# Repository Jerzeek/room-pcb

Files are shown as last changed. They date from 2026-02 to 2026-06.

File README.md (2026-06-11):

# Room Sensor



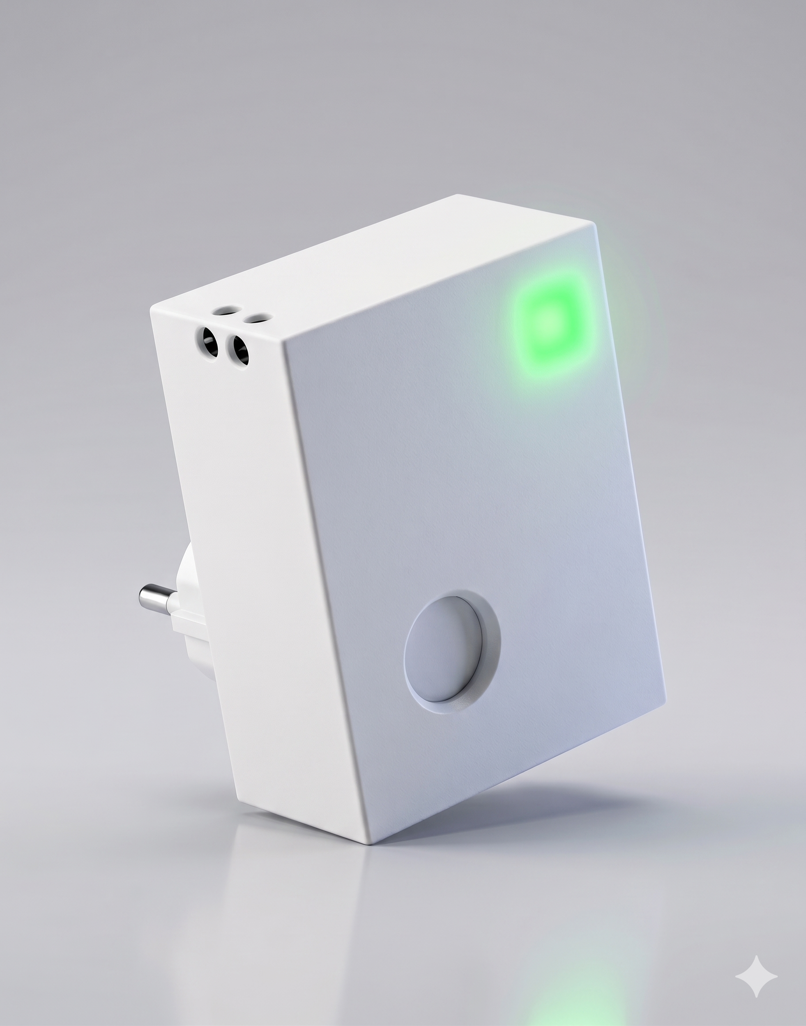
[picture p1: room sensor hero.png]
Room Sensor


An open-source, mains-powered room sensor PCB based on the ESP32-C6. Measures CO2, temperature, humidity, illuminance, and presence, with a WS2812B LED status indicator. Supports both **ESPHome** (Wi-Fi / Home Assistant) and **Zigbee** firmware out of the box.

---

> **WARNING — MAINS AC VOLTAGE**
>
> This board connects directly to mains AC (100–240 V). Incorrect wiring or handling can cause **electric shock, fire, or death**. This project is intended for **experienced makers** who are comfortable working with mains-voltage electronics. Always work with the power disconnected. Comply with all local electrical codes. The authors accept no liability for any damage or injury.

---

## Features

- Direct mains AC input via onboard HLK-5M05 AC-DC converter (no external power brick needed)
- CO2, temperature, and humidity via CozIR sensor (NDIR CO2, UART)
- Ambient light via BH1750 (I2C, lux)
- Secondary temperature + humidity via AHT20 (I2C)
- Presence/occupancy detection via LD2410 mmWave radar (UART)
- Visual CO2 status indicator: 2× WS2812B addressable LEDs
- Polyfuse (F1) overcurrent protection
- Reset/factory-reset button (BOOT pin)
- ESP32-C6 SuperMini module — supports both Wi-Fi 6 and native Zigbee
- Two equal-priority firmware options: ESPHome and Zigbee (Arduino)

## Sensors

| Sensor | Part | Interface | Measures |
|---|---|---|---|
| CO2 (NDIR) | CozIR | UART (9600 baud) | CO2 (ppm), temperature, humidity |
| Ambient light | BH1750FVI-TR | I2C (0x23) | Illuminance (lux) |
| Temperature + humidity | AHT20 | I2C | Temperature (°C), humidity (%RH) |
| Presence / occupancy | LD2410 | UART (256000 baud) | Presence, moving/stationary targets |
| Status LEDs | WS2812B-2020 × 2 | GPIO (RMT) | CO2 level indicator |

## Hardware

### Main components

| Ref | Part | Description |
|---|---|---|
| U5 | ESP32-C6 SuperMini | Main MCU — Wi-Fi 6 + Zigbee |
| PS1 | HLK-5M05 | AC-DC converter, 100–240 V AC → 5 V DC |
| U1 | CozIR | NDIR CO2 / temp / humidity sensor |
| U2 | BH1750FVI-TR | Ambient light sensor |
| U3 | AHT20 | Temperature + humidity sensor |
| J4 | 5-pin header (1.27 mm) | LD2410 radar connection |
| D1, D2 | WS2812B-2020 | Addressable RGB LEDs |
| F1 | Polyfuse | Overcurrent protection |

### Versions

| Version | Notes |
|---|---|
| v4.1 | Current release — improved silkscreen |
| v4 | Production-ready layout |
| v3.1 | Earlier revision (3D model reference) |
| v3 | Initial working prototype |

## Building / Ordering

All files needed to order and assemble the PCB are in `pcb/production/`:

| File | Purpose |
|---|---|
| `room-pcb.zip` | Gerber + drill files — upload directly to your PCB fab (JLCPCB, PCBWay, etc.) |
| `bom.csv` | Bill of materials for component sourcing |
| `positions.csv` | Pick-and-place / component placement file |
| `designators.csv` | Designator reference |
| `netlist.ipc` | IPC-D-356 netlist for electrical testing |

KiCad source files are in `pcb/`.

## Firmware

### ESPHome (Wi-Fi / Home Assistant)

Configuration is in `code/esphome/room_sensor.yaml`. A custom ESPHome component for the CozIR sensor is included under `code/esphome/components/cozir/`.

1. Copy `room_sensor.yaml` and the `components/` directory to your ESPHome config folder.
2. Create a `secrets.yaml` with your `wifi_ssid` and `wifi_password`.
3. Flash via `esphome run room_sensor.yaml`.

The LED indicates CO2 level:

| Color | CO2 |
|---|---|
| Green | < 800 ppm (good) |
| Yellow | 800–1200 ppm (moderate) |
| Red | > 1200 ppm (poor) |

Calibration buttons are exposed to Home Assistant:
- **Calibrate Fresh Air (400 ppm)** — use outdoors in clean air
- **Calibrate Nitrogen (0 ppm)** — use with pure N2

### Zigbee (Arduino / esp32-arduino)

Sketch is in `code/combined_working_zigbee/combined_working_zigbee.ino`. Requires the Arduino ESP32 core (≥ 3.x) with Zigbee support.

**Before flashing:**
- In Arduino IDE → Tools → Zigbee Mode → select **Zigbee ED (End Device)**
- Select a partition scheme that includes Zigbee (e.g., *Zigbee 4MB with spiffs*)

The sketch exposes four Zigbee endpoints:

| Endpoint | Cluster | Data |
|---|---|---|
| 10 | CO2 (CarbonDioxide) | CO2 ppm |
| 11 | Temp + Humidity | Temperature °C, humidity %RH |
| 13 | Illuminance | Lux |
| 14 | Occupancy | Presence (boolean) |

Hold the BOOT button for 3 seconds to perform a Zigbee factory reset.

## Repository layout

```
room-pcb/
├── pcb/                  KiCad project files
│   └── production/       Gerbers, BOM, placement — ready to order
├── code/
│   ├── esphome/          ESPHome YAML + custom CozIR component
│   └── combined_working_zigbee/  Arduino Zigbee sketch
├── 3Dmodels/             STEP model of the enclosure / board
├── CHANGELOG.md
├── CONTRIBUTING.md
└── LICENSE
```

## License

Hardware (PCB and schematics) is licensed under the **CERN Open Hardware Licence Version 2 — Strongly Reciprocal (CERN OHL-S v2)**. See [LICENSE](LICENSE) for the full text.

Firmware is licensed under the same CERN OHL-S v2 unless a file header states otherwise.

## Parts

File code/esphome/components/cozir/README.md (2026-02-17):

# Cozir CO2 Sensor Component for ESPHome

This component allows using Cozir CO2 sensors (like CozIR-A) with ESPHome via UART.

## Configuration

```yaml
uart:
  tx_pin: GPIO1
  rx_pin: GPIO3
  baud_rate: 9600

sensor:
  - platform: cozir
    id: my_cozir
    co2:
      name: "Cozir CO2"
    temperature:
      name: "Cozir Temperature"
    humidity:
      name: "Cozir Humidity"
    update_interval: 60s
```

## Calibration

You can calibrate the sensor using `lambda` calls or by exposing template buttons.

### Fresh Air Calibration (400ppm)
```yaml
button:
  - platform: template
    name: "Calibrate Fresh Air"
    on_press:
      - lambda: 'id(my_cozir)->calibrate_fresh_air();'
```

### Nitrogen Calibration (0ppm)
```yaml
button:
  - platform: template
    name: "Calibrate Nitrogen"
    on_press:
      - lambda: 'id(my_cozir)->calibrate_nitrogen();'
```

### Known Gas Calibration
```yaml
# Example using a template number to set target PPM
number:
  - platform: template
    id: target_ppm
    name: "Target Calibration PPM"
    min_value: 0
    max_value: 5000
    step: 10
    optimistic: true
    set_action: []

button:
  - platform: template
    name: "Calibrate Known Gas"
    on_press:
      - lambda: 'id(my_cozir)->calibrate_known_gas((uint16_t)id(target_ppm).state);'
```

## Notes
- The component automatically detects the PPM multiplier (1, 10, or 100) on each update.
- Ensure the sensor is powered correctly (3.3V typically).

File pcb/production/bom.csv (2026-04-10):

Designator | Footprint | Quantity | Value | LCSC Part #
C1 | 0805 | 1 | 1U
C4, C5, C6 | 0805 | 3 | 0.1U
D1, D2 | LED_WS2812B-2020_PLCC4_2.0x2.0mm | 2 | WS2812B
F1 | Fuse_Bourns_MF-RG300 | 1 | Polyfuse
J2 | JST_PH_S2B-PH-SM4-TB_1x02-1MP_P2.00mm_Horizontal | 1 | Conn_01x02
J3 | JST_SH_SM04B-SRSS-TB_1x04-1MP_P1.00mm_Horizontal | 1 | Conn_01x04
J4 | PinHeader_1x05_P1.27mm_Vertical | 1 | Conn_01x05
J5, J6 | PinHeader_1x04_P2.54mm_Vertical | 2 | Conn_01x04
PS1 | Converter_ACDC_Hi-Link_HLK-5Mxx | 1 | HLK-5M05
R1 | 0805 | 1 | 1K
R5, R6, R7 | 0805 | 3 | 10K
TP1, TP2, TP3 | TestPoint_THTPad_D1.5mm_Drill0.7mm | 3 | TestPoint
U1 | cozir | 1 | COZIR
U2 | XDCR_BH1750FVI-TR | 1 | BH1750FVI-TR
U3 | PSON100P300X300X110-6N | 1 | AHT20
U5 | MODULE_ESP32-C6_SUPERMINI_TH | 1 | ESP32-C6_SUPERMINI_TH

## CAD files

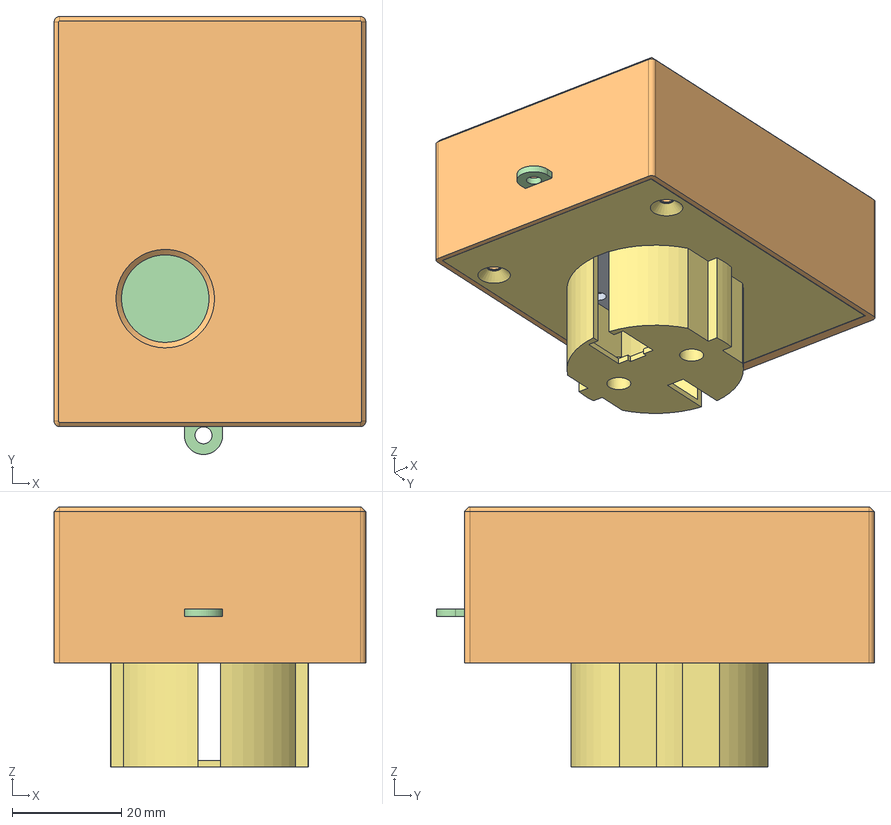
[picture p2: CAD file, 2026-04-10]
3Dmodels/home sensor v31.step
57.0 x 80.1 x 47.5 mm
pcb
housing
hilink acdc
cozir
LD2410
esp32 c6 super mini
ac

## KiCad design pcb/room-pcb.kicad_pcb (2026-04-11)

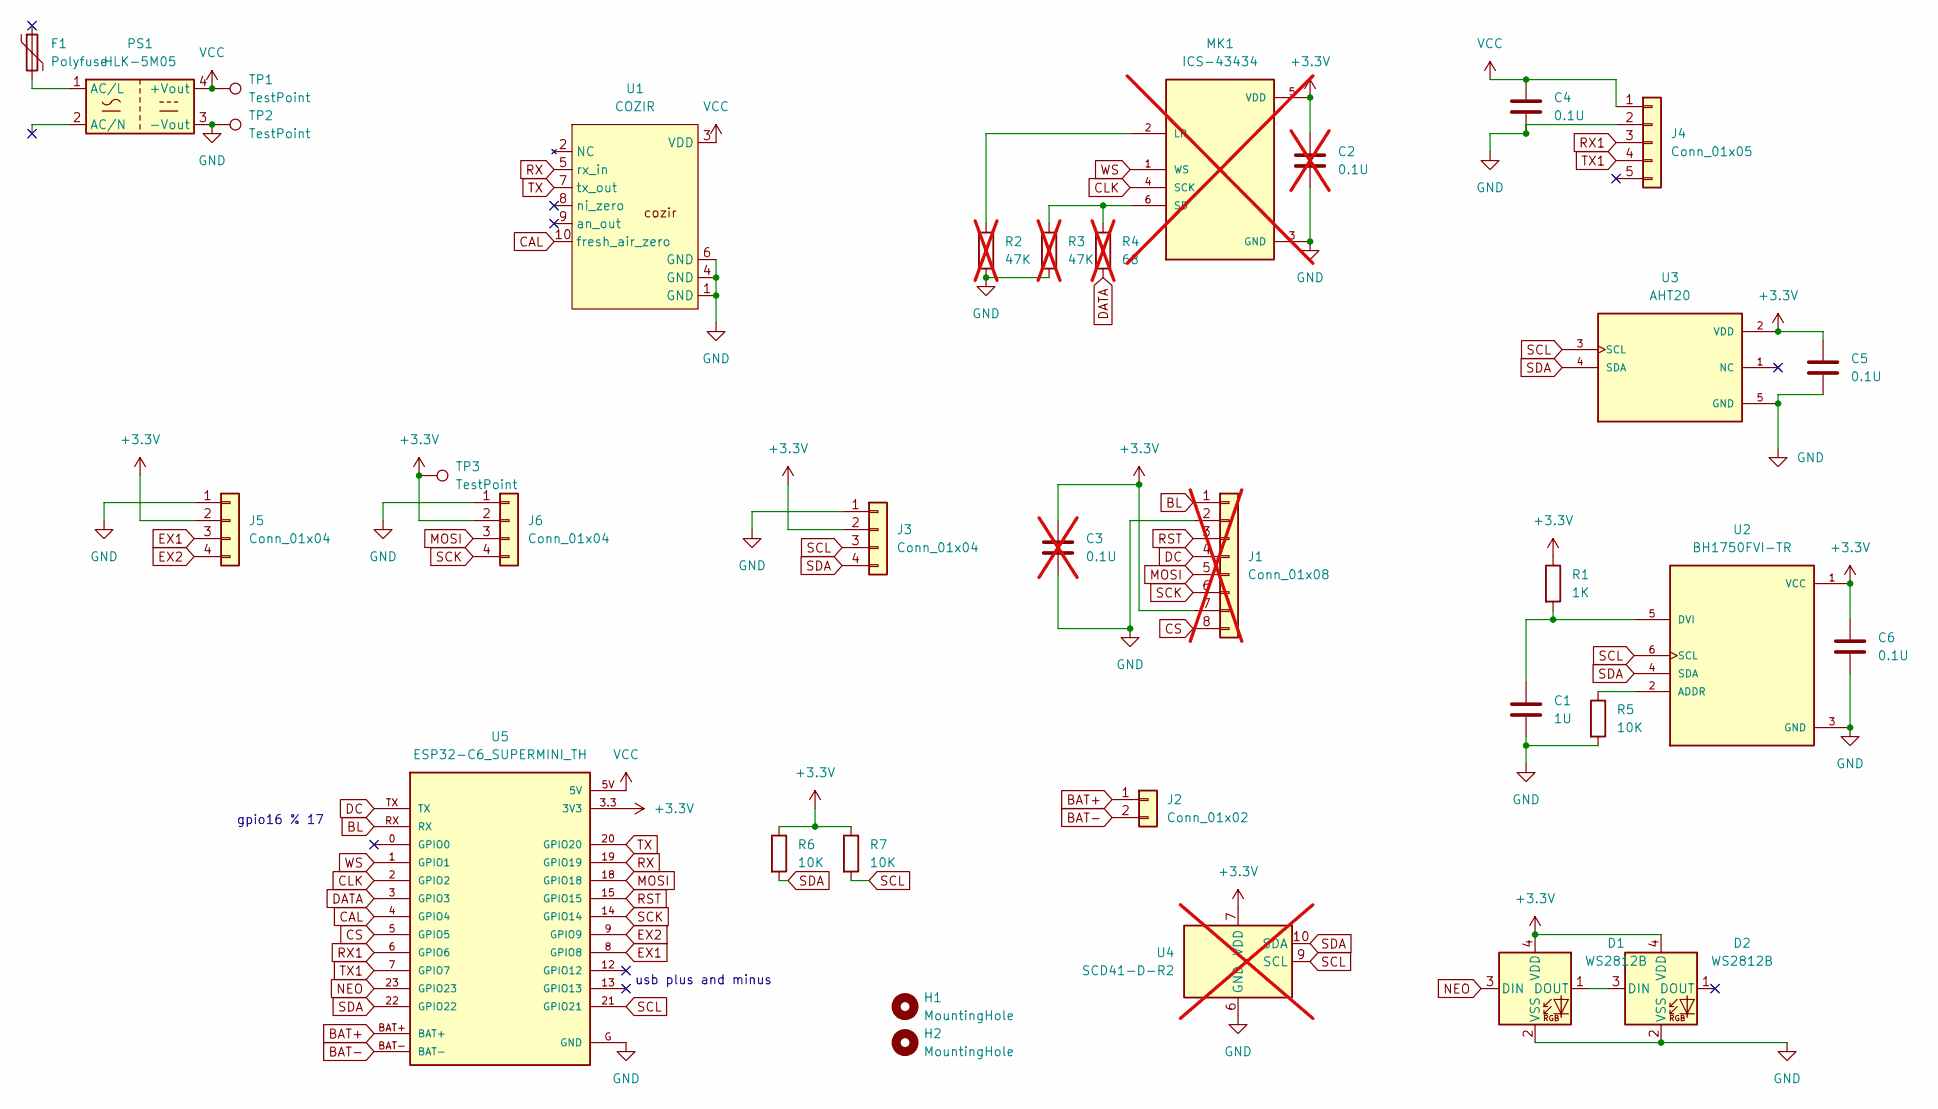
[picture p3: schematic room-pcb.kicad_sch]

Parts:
C1: 1U; C_0805_2012Metric
C2, C3: 0.1U; C_0805_2012Metric; not fitted
C4, C5, C6: 0.1U; C_0805_2012Metric
D1, D2: WS2812B; LED_WS2812B-2020_PLCC4_2.0x2.0mm
F1: Polyfuse; Fuse_Bourns_MF-RG300
H1, H2: MountingHole; MountingHole_3.2mm_M3
J1: Conn_01x08; Hirose_FH12-8S-0.5SH_1x08-1MP_P0.50mm_Horizontal; not fitted
J2: Conn_01x02; JST_PH_S2B-PH-SM4-TB_1x02-1MP_P2.00mm_Horizontal
J3: Conn_01x04; JST_SH_SM04B-SRSS-TB_1x04-1MP_P1.00mm_Horizontal
J4: Conn_01x05; PinHeader_1x05_P1.27mm_Vertical
J5, J6: Conn_01x04; PinHeader_1x04_P2.54mm_Vertical
MK1: ICS-43434; MIC_ICS-43434; not fitted
PS1: HLK-5M05; Converter_ACDC_Hi-Link_HLK-5Mxx
R1: 1K; R_0805_2012Metric
R2, R3: 47K; R_0805_2012Metric; not fitted
R4: 68; R_0805_2012Metric; not fitted
R5, R6, R7: 10K; R_0805_2012Metric
TP1, TP2, TP3: TestPoint; TestPoint_THTPad_D1.5mm_Drill0.7mm
U1: COZIR; cozir
U2: BH1750FVI-TR; XDCR_BH1750FVI-TR; PARTREV D
U3: AHT20; PSON100P300X300X110-6N; PARTREV V1.0
U4: SCD41-D-R2; Sensirion_SCD4x-1EP_10.1x10.1mm_P1.25mm_EP4.8x4.8mm; not fitted
U5: ESP32-C6_SUPERMINI_TH; MODULE_ESP32-C6_SUPERMINI_TH

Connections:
+3.3V: C2.1, C3.1, C5.1, C6.1, D1.4 (VDD), D2.4 (VDD), J1.7, J3.2, J5.2, J6.2, MK1.5 (VDD), R1.1, R6.1, R7.1, TP3.1, U2.1 (VCC), U3.2 (VDD), U4.7 (VDD), U4.19 (VDD), U5.3.3 (3V3)
BAT+: J2.1, U5.BAT+
BAT-: J2.2, U5.BAT-
BL: J1.1, U5.RX
CAL: U1.10 (fresh_air_zero), U5.4 (GPIO4)
CLK: MK1.4 (SCK), U5.2 (GPIO2)
CS: J1.8, U5.5 (GPIO5)
DATA: R4.2, U5.3 (GPIO3)
DC: J1.4, U5.TX
EX1: J5.3, U5.8 (GPIO8)
EX2: J5.4, U5.9 (GPIO9)
GND: C1.2, C2.2, C3.2, C4.2, C5.2, C6.2, D1.2 (VSS), D2.2 (VSS), J1.2, J3.1, J4.2, J5.1, J6.1, MK1.3 (GND), PS1.3 (-Vout), R2.2, R3.2, R5.2, TP2.1, U1.1 (GND), U1.4 (GND), U1.6 (GND), U2.3 (GND), U3.5 (GND), U4.6 (GND), U4.20 (GND), U4.21 (GND), U5.G (GND)
MOSI: J1.5, J6.3, U5.18 (GPIO18)
NEO: D1.3 (DIN), U5.23 (GPIO23)
unnamed: D1.1 (DOUT), D2.3 (DIN)
unnamed: MK1.2 (LR), R2.1
unnamed: MK1.6 (SD), R3.1, R4.1
unnamed: F1.2, PS1.1 (AC/L)
unnamed: R5.1, U2.2 (ADDR)
unnamed: C1.1, R1.2, U2.5 (DVI)
RST: J1.3, U5.15 (GPIO15)
RX: U1.5 (rx_in), U5.19 (GPIO19)
RX1: J4.3, U5.6 (GPIO6)
SCK: J1.6, J6.4, U5.14 (GPIO14)
SCL: J3.3, R7.2, U2.6 (SCL), U3.3 (SCL), U4.9 (SCL), U5.21 (GPIO21)
SDA: J3.4, R6.2, U2.4 (SDA), U3.4 (SDA), U4.10 (SDA), U5.22 (GPIO22)
TX: U1.7 (tx_out), U5.20 (GPIO20)
TX1: J4.4, U5.7 (GPIO7)
VCC: C4.1, J4.1, PS1.4 (+Vout), TP1.1, U1.3 (VDD), U5.5V
WS: MK1.1 (WS), U5.1 (GPIO1)

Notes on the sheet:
gpio16 % 17
usb plus and minus

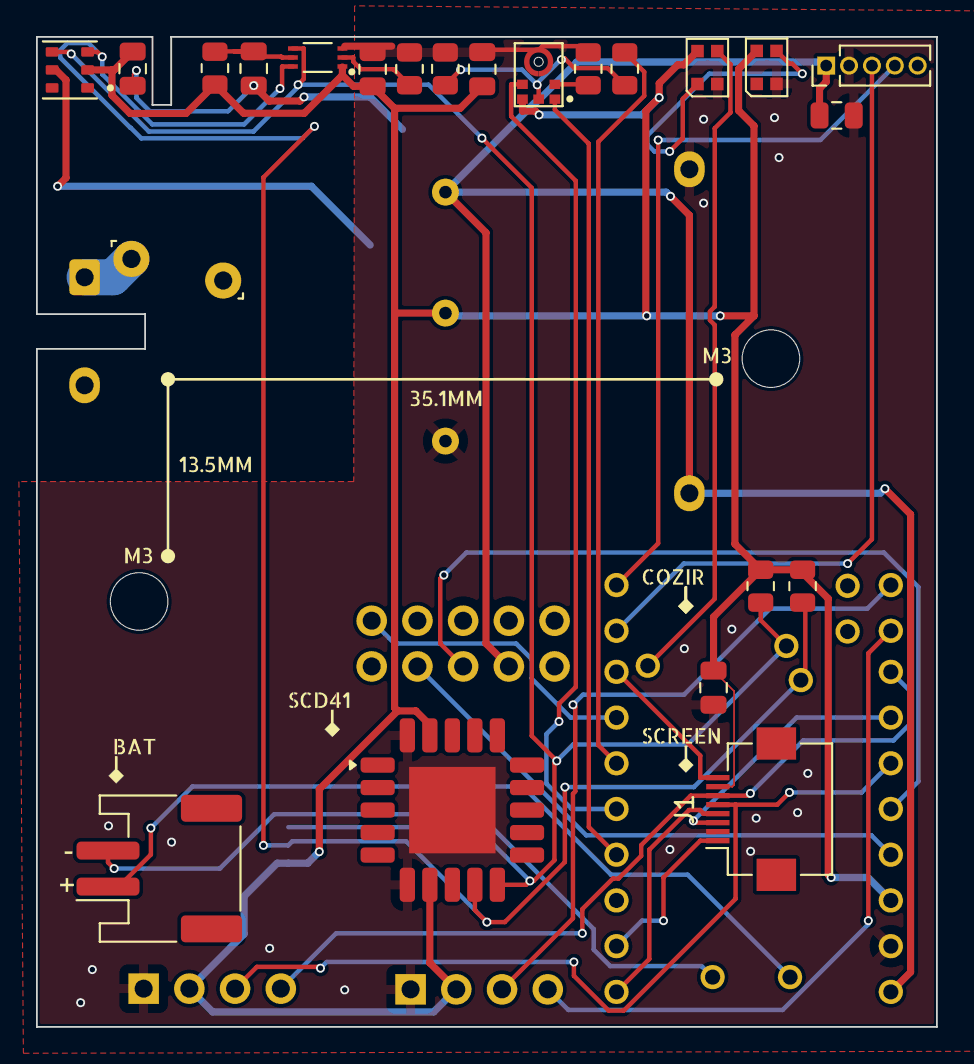
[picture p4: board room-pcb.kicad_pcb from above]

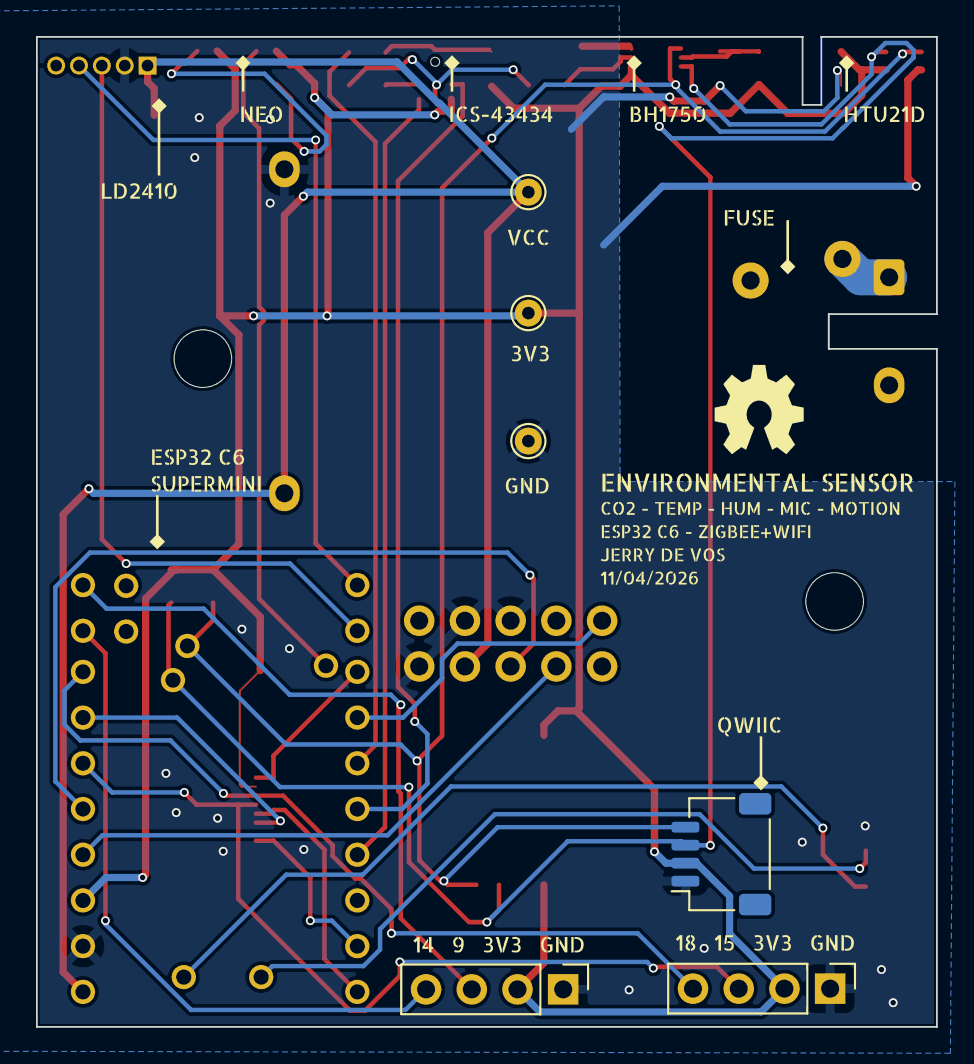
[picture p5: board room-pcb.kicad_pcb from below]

Board: 2 copper layers, 50.0 x 55.0 mm, 34 parts (7 on the bottom side), 30 nets.

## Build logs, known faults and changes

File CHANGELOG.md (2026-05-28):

# Changelog

All notable changes to this project will be documented in this file.

The format is based on [Keep a Changelog](https://keepachangelog.com/en/1.1.0/).
Hardware versions follow a `vMAJOR.MINOR` scheme; minor bumps are layout/silkscreen changes, major bumps indicate schematic changes.

---

## [Unreleased]

---

## [v4.1] - 2026-04

### Changed
- Improved silkscreen legibility — component labels and reference designators cleaned up across the board.
- Updated Gerbers and production files to match v4.1 layout.

---

## [v4] - 2026-03

### Added
- Production-ready layout with all sensors placed and routed.
- HLK-5M05 footprint corrected and mains clearances verified.
- Polyfuse (F1) added for overcurrent protection on the 5 V rail.
- LD2410 radar header (J4, 1.27 mm pitch, 5-pin) added.
- JST-SH connector (J3) for I2C breakout.
- Two WS2812B-2020 LEDs (D1, D2) as CO2 status indicators.
- Combined working Zigbee sketch (`combined_working_zigbee.ino`) with CO2, temp/humidity, illuminance, and occupancy endpoints.
- ESPHome configuration (`room_sensor.yaml`) with custom CozIR component.

### Changed
- Switched MCU to ESP32-C6 SuperMini module for native Zigbee support.
- Resolved KiCad merge conflicts from concurrent edits.

---

## [v3.1] - 2026-02

### Changed
- Minor layout adjustments (captured in STEP model `home sensor v31.step`).
- Test points (TP1–TP3) repositioned for easier probing.

---

## [v3] - 2026-01

### Added
- Initial working prototype with all sensor ICs populated.
- First ESPHome YAML and CozIR Arduino library integrated.
- 3D model added to repository.

---

[Unreleased]: https://github.com/Jerzeek/room-pcb/compare/v4.1...HEAD
[v4.1]: https://github.com/Jerzeek/room-pcb/compare/v4...v4.1
[v4]: https://github.com/Jerzeek/room-pcb/compare/v3.1...v4
[v3.1]: https://github.com/Jerzeek/room-pcb/compare/v3...v3.1
[v3]: https://github.com/Jerzeek/room-pcb/releases/tag/v3

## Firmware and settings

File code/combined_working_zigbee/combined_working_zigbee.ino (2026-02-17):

/*
 * Combined Room Sensors Sketch (Zigbee End Device)
 * - Cozir CO2 Sensor (SoftwareSerial on 20/19)
 * - LD2410 Radar Sensor (Hardware Serial)
 * - BH1750 Light Sensor (I2C on 22/21)
 * - NeoPixel Status LED (Pin 8)
 * - Zigbee Endpoints: CO2, Temp+Hum, Light, Occupancy
 *
 * NOTE: Select "Zigbee ED (End Device)" in Tools -> Zigbee Mode
 * NOTE: Select a Partition Scheme with Zigbee (e.g., "Zigbee 4MB with spiffs")
 */

#ifndef ZIGBEE_MODE_ED
#error "Zigbee end device mode is not selected in Tools->Zigbee mode"
#endif

#include "Arduino.h"
#include "Zigbee.h"
#include <Wire.h>
#include <SoftwareSerial.h>
#include <Adafruit_NeoPixel.h>

// --- Libraries ---
#include "cozir.h"
#include <ld2410.h>
#include <BH1750.h>

// --- FILTERING CLASS ---
template <typename T, int SIZE>
class MovingQuantile {
  T buffer[SIZE];
  uint8_t idx = 0;
  uint8_t count = 0;
  float quantile;

public:
  MovingQuantile(float q = 0.5) : quantile(q) {}

  void add(T value) {
    buffer[idx] = value;
    idx = (idx + 1) % SIZE;
    if (count < SIZE) count++;
  }

  T get() {
    if (count == 0) return 0;
    T sorted[SIZE];
    for (uint8_t i = 0; i < count; i++) sorted[i] = buffer[i];
    // Simple Bubble Sort
    for (uint8_t i = 0; i < count - 1; i++) {
      for (uint8_t j = 0; j < count - i - 1; j++) {
        if (sorted[j] > sorted[j + 1]) {
          T temp = sorted[j];
          sorted[j] = sorted[j + 1];
          sorted[j + 1] = temp;
        }
      }
    }
    int qIdx = (int)(quantile * (count - 1));
    return sorted[qIdx];
  }
};

// --- ZIGBEE CONFIG ---
#define EP_CO2 10
#define EP_TEMP_HUM 11  // Combined endpoint for Temp & Humidity
#define EP_LIGHT 13
#define EP_OCCUPANCY 14

uint8_t button = BOOT_PIN; 

// Create Zigbee Sensor Objects
ZigbeeCarbonDioxideSensor zbCo2(EP_CO2);
ZigbeeTempSensor          zbTempHum(EP_TEMP_HUM); // Handles both Temp and Hum
ZigbeeIlluminanceSensor   zbLight(EP_LIGHT);
ZigbeeOccupancySensor     zbOcc(EP_OCCUPANCY);

// --- PIN DEFINITIONS & OBJECTS ---

// 1. Cozir CO2 (SoftwareSerial)
SoftwareSerial sws(20, 19); //RX TX
COZIR czr(&sws);
C0ZIRParser czrp;

// 2. BH1750 Light Sensor (I2C)
BH1750 lightMeter(0x5C);

// 3. NeoPixel (Pin 8)
#define NEOPIXEL_PIN 8
#define NUMPIXELS 1
Adafruit_NeoPixel pixels(NUMPIXELS, NEOPIXEL_PIN, NEO_GRB + NEO_KHZ800);

// 4. LD2410 Radar (Hardware Serial)
#define MONITOR_SERIAL Serial
#define RADAR_SERIAL Serial1
#define RADAR_RX_PIN 7
#define RADAR_TX_PIN 5 
ld2410 radar;

// --- TIMERS ---
uint32_t lastRadarReport = 0;
uint32_t lastCozirReport = 0;
uint32_t lastLightReport = 0;

// --- FILTERING ---
MovingQuantile<uint32_t, 5> co2Filter(0.5);
MovingQuantile<float, 5> tempFilter(0.5);
MovingQuantile<float, 5> humFilter(0.5);
MovingQuantile<float, 5> lightFilter(0.5);

const uint32_t RADAR_REPORT_INTERVAL = 1000;
const uint32_t COZIR_REPORT_INTERVAL = 5000;
const uint32_t LIGHT_REPORT_INTERVAL = 20000;

void setup()
{
  // 1. Monitor Serial
  MONITOR_SERIAL.begin(115200);
  delay(2000);
  MONITOR_SERIAL.println(F("\n--- Combined Room Sensors (Zigbee ED) Init ---"));

  // 2. Button Init
  pinMode(button, INPUT_PULLUP);

  // 3. NeoPixel Init
  MONITOR_SERIAL.println(F("[NeoPixel] Init..."));
  pixels.begin();
  pixels.show(); 

  // 4. Cozir Setup
  MONITOR_SERIAL.println(F("[Cozir] Init..."));
  sws.begin(9600);
  czr.init();
  czrp.init();
  czr.setOperatingMode(CZR_STREAMING);
  czr.setOutputFields(CZR_DEFAULT);

  // 5. BH1750 Setup
  MONITOR_SERIAL.println(F("[BH1750] Init..."));
  Wire.begin(22, 21); 
  if (lightMeter.begin()) {
    MONITOR_SERIAL.println(F("[BH1750] OK"));
  } else {
    MONITOR_SERIAL.println(F("[BH1750] Error initialising"));
  }

  // 6. Radar Setup
  MONITOR_SERIAL.print(F("[Radar] Connecting to RX:"));
  MONITOR_SERIAL.print(RADAR_RX_PIN);
  MONITOR_SERIAL.print(F(" TX:"));
  MONITOR_SERIAL.println(RADAR_TX_PIN);

  #if defined(ESP32)
    RADAR_SERIAL.begin(256000, SERIAL_8N1, RADAR_RX_PIN, RADAR_TX_PIN);
  #elif defined(__AVR_ATmega32U4__)
    RADAR_SERIAL.begin(256000);
  #endif

  if(radar.begin(RADAR_SERIAL))
  {
    MONITOR_SERIAL.println(F("[Radar] OK"));
  }
  else
  {
    MONITOR_SERIAL.println(F("[Radar] Not connected"));
  }

  // 7. Zigbee Setup
  MONITOR_SERIAL.println(F("[Zigbee] Init..."));
  
  // Set Info
  zbCo2.setManufacturerAndModel("Espressif", "MultiSensor_CO2");
  
  // Configure Combined Temp/Hum Sensor
  zbTempHum.setManufacturerAndModel("Espressif", "MultiSensor_TempHum");
  // Enable Humidity on this sensor (Min:0%, Max:100%, Tolerance:1%)
  zbTempHum.addHumiditySensor(0, 100, 1.0); 

  zbLight.setManufacturerAndModel("Espressif", "MultiSensor_Light");
  zbOcc.setManufacturerAndModel("Espressif", "MultiSensor_Occ");

  // Add Endpoints
  Zigbee.addEndpoint(&zbCo2);
  Zigbee.addEndpoint(&zbTempHum);
  Zigbee.addEndpoint(&zbLight);
  Zigbee.addEndpoint(&zbOcc);

  if (!Zigbee.begin()) {
    MONITOR_SERIAL.println(F("[Zigbee] Failed to start! Rebooting..."));
    ESP.restart();
  } else {
    MONITOR_SERIAL.println(F("[Zigbee] Started successfully!"));
  }
  
  MONITOR_SERIAL.println(F("[Zigbee] Connecting to network..."));
  while (!Zigbee.connected()) {
    MONITOR_SERIAL.print(".");
    delay(100);
  }
  MONITOR_SERIAL.println();
  
  // Configure Reporting
  zbCo2.setReporting(1, 30, 10);     
  
  // Temp Reporting (Min, Max, Delta)
  zbTempHum.setReporting(1, 30, 0.5);   
  // Humidity Reporting (Min, Max, Delta) - Separate function
  zbTempHum.setHumidityReporting(1, 30, 1.0);
  
  zbLight.setReporting(1, 30, 50);   
  
  // NOTE: zbOcc (Binary Sensor) usually reports on state change automatically. 
  // Removed setReporting() as it is not supported by the Occupancy class.

  MONITOR_SERIAL.println(F("--- Setup Complete ---\n"));
}

void loop()
{
  // --- READ RADAR (Must be called frequently) ---
  radar.read();

  uint32_t currentMillis = millis();

  // --- REPORT RADAR & UPDATE NEOPIXEL ---
  if(radar.isConnected() && (currentMillis - lastRadarReport > RADAR_REPORT_INTERVAL))
  {
    lastRadarReport = currentMillis;
    bool presence = radar.presenceDetected();
    
    // Update Zigbee
    zbOcc.setOccupancy(presence);
    
    if(presence)
    {
      pixels.setPixelColor(0, pixels.Color(255, 0, 0)); // Red
      
      // if(radar.stationaryTargetDetected())
      // {
      //   MONITOR_SERIAL.print(F("[Radar] Stat Dist: "));
      //   MONITOR_SERIAL.print(radar.stationaryTargetDistance());
      //   MONITOR_SERIAL.print(F("cm Energy: "));
      //   MONITOR_SERIAL.print(radar.stationaryTargetEnergy());
      //   MONITOR_SERIAL.print(' ');
      // }
      // if(radar.movingTargetDetected())
      // {
      //   MONITOR_SERIAL.print(F("[Radar] Mov Dist: "));
      //   MONITOR_SERIAL.print(radar.movingTargetDistance());
      //   MONITOR_SERIAL.print(F("cm Energy: "));
      //   MONITOR_SERIAL.print(radar.movingTargetEnergy());
      // }
      // MONITOR_SERIAL.println();
    }
    else
    {
      pixels.setPixelColor(0, pixels.Color(0, 255, 0)); // Green
      MONITOR_SERIAL.println(F("[Radar] No target"));
    }
    pixels.show();
  }

  // --- READ COZIR STREAM ---


  // --- REPORT COZIR (Serial Monitor) ---
  if (currentMillis - lastCozirReport > COZIR_REPORT_INTERVAL) {
    lastCozirReport = currentMillis;

    while (sws.available()) {
      int field = czrp.nextChar(sws.read());
      if (field != 0) {
        // Filter CO2 (Max 4000)
        if (field == 'Z') {
          uint32_t co2 = czrp.CO2();
          if (co2 <= 4000) {
            co2Filter.add(co2);
            zbCo2.setCarbonDioxide(co2Filter.get());
          }
        }
        // Filter Temp (0-100 C)
        else if (field == 'T') {
          float t = czrp.celsius();
          if (t >= 0 && t <= 100) {
            tempFilter.add(t);
            zbTempHum.setTemperature(tempFilter.get());
          }
        }
        // Filter Humidity
        else if (field == 'H') {
          float h = czrp.humidity();
          if (h >= 0 && h <= 100) {
            humFilter.add(h);
            zbTempHum.setHumidity(humFilter.get());
          }
        }
      }
    }
    uint32_t c = czrp.CO2(); 
    float t = czrp.celsius();
    float h = czrp.humidity();

    MONITOR_SERIAL.print(F("[Cozir] Temp: "));
    MONITOR_SERIAL.print(t);
    MONITOR_SERIAL.print(F(" C\tHum: "));
    MONITOR_SERIAL.print(h);
    MONITOR_SERIAL.print(F("%\tCO2: "));
    MONITOR_SERIAL.println(c);
  }

  // --- REPORT LIGHT ---
  if (currentMillis - lastLightReport > LIGHT_REPORT_INTERVAL) {
    lastLightReport = currentMillis;
      
      float lux = lightMeter.readLightLevel();
      lightFilter.add(lux);
      float filteredLux = lightFilter.get();
      
      // 1. Calculate the Zigbee "MeasuredValue"
      // Formula: 10000 * log10(Lux) + 1
      uint16_t zigbeeRaw;
      
      if (filteredLux <= 0.0001) { 
        zigbeeRaw = 0; // Darkness
      } else if (filteredLux > 1000000) {
        zigbeeRaw = 0xfffe; // Maximum defined value
      } else {
        zigbeeRaw = (uint16_t)(10000 * log10(filteredLux) + 1);
      }

      // 2. Log both for debugging
      MONITOR_SERIAL.print(F("[Light] Real Lux: "));
      MONITOR_SERIAL.println(lux);
      // MONITOR_SERIAL.print(F(" | Zigbee Raw: "));
      // MONITOR_SERIAL.println(zigbeeRaw);
      
      // 3. Send the RAW value to Zigbee
      zbLight.setIlluminance(zigbeeRaw);
  }

  // --- BUTTON (Factory Reset) ---
  if (digitalRead(button) == LOW) { 
    delay(100); // Debounce
    uint32_t startTime = millis();
    while (digitalRead(button) == LOW) {
      delay(50);
      if ((millis() - startTime) > 3000) {
        MONITOR_SERIAL.println(F("Resetting Zigbee to factory and rebooting..."));
        pixels.setPixelColor(0, pixels.Color(0, 0, 255)); // Blue for reset
        pixels.show();
        delay(1000);
        Zigbee.factoryReset();
      }
    }
    // Manually trigger report on button click for testing
    zbCo2.report();
    zbTempHum.report(); // Reports both Temp & Hum
    zbLight.report();
    zbOcc.report();
  }
}

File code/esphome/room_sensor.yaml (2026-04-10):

esphome:
  name: room-sensor3
  friendly_name: room_sensor3

esp32:
  board: esp32-c6-devkitc-1
  framework:
    type: esp-idf

# Enable logging
logger:

# Enable Home Assistant API
api:
  encryption:
    key: "x7dmEtUnraoTiORhJYHz7vtC5tRRsgen1eWqUg1EyWk="

ota:
  - platform: esphome
    password: "e07e7f460b2b8dd917edea576c4c2a43"

wifi:
  ssid: !secret wifi_ssid
  password: !secret wifi_password

  # Enable fallback hotspot (captive portal) in case wifi connection fails
  ap:
    ssid: "Room-Sensor Fallback Hotspot"
    password: "viXdy4Uy5Z67"

captive_portal:

external_components:
  - source:
      type: local
      path: components

uart:

  - id: uart_bus
    tx_pin: GPIO19
    rx_pin: GPIO20
    baud_rate: 9600

  - id: uart_bus_ld2410
    tx_pin: GPIO5
    rx_pin: GPIO7
    baud_rate: 256000 
    parity: NONE
    stop_bits: 1

i2c:
  sda: GPIO22
  scl: GPIO21

# Example configuration entry
ld2410:
  - uart_id: uart_bus_ld2410

light:
  - platform: esp32_rmt_led_strip
    rgb_order: GRB
    id: co2_led
    pin: GPIO23
    num_leds: 2
    chipset: ws2812
    name: "My Light"

binary_sensor:
  - platform: ld2410
    has_target:
      name: Presence
    # has_moving_target:
    #   name: Moving Target
    # has_still_target:
    #   name: Still Target
    # out_pin_presence_status:
    #   name: Out pin presence status

sensor:
  # - platform: ld2410
  #   light:
  #     name: Light
  #   moving_distance:
  #     name: Moving Distance
  #   still_distance:
  #     name: Still Distance
  #   moving_energy:
  #     name: Move Energy
  #   still_energy:
  #     name: Still Energy
  #   detection_distance:
  #     name: Detection Distance
  #   g0:
  #     move_energy:
  #       name: G0 move energy
  #     still_energy:
  #       name: G0 still energy
  #   g1:
  #     move_energy:
  #       name: G1 move energy
  #     still_energy:
  #       name: G1 still energy
  #   g2:
  #     move_energy:
  #       name: G2 move energy
  #     still_energy:
  #       name: G2 still energy
  #   g3:
  #     move_energy:
  #       name: G3 move energy
  #     still_energy:
  #       name: G3 still energy
  #   g4:
  #     move_energy:
  #       name: G4 move energy
  #     still_energy:
  #       name: G4 still energy
  #   g5:
  #     move_energy:
  #       name: G5 move energy
  #     still_energy:
  #       name: G5 still energy
  #   g6:
  #     move_energy:
  #       name: G6 move energy
  #     still_energy:
  #       name: G6 still energy
  #   g7:
  #     move_energy:
  #       name: G7 move energy
  #     still_energy:
  #       name: G7 still energy
  #   g8:
  #     move_energy:
  #       name: G8 move energy
  #     still_energy:
  #       name: G8 still energy
  - platform: cozir
    uart_id: uart_bus
    id: my_cozir  # Required for calibration actions
    co2:
      name: "Cozir CO2"
      filters:
      - exponential_moving_average:
          alpha: 0.1
          send_every: 2
          send_first_at: 1
      on_value_range:
          - below: 800.0
            then:
              - light.turn_on:
                  id: co2_led
                  brightness: 100%
                  red: 0.0
                  green: 0.7
                  blue: 0.0
          - above: 800.0
            below: 1200.0
            then:
              - light.turn_on:
                  id: co2_led
                  brightness: 100%
                  red: 0.8
                  green: 0.7
                  blue: 0.0
          - above: 1200.0
            then:
              - light.turn_on:
                  id: co2_led
                  brightness: 100%
                  red: 0.7
                  green: 0.0
                  blue: 0.0
    temperature:
      name: "Cozir Temperature"
      # Example configuration entry
      filters:
        - offset: -5.0
    humidity:
      name: "Cozir Humidity"
    update_interval: 30s
  - platform: bh1750
    name: "BH1750 Illuminance"
    address: 0x23
    update_interval: 60s
  - platform: aht10
    variant: AHT20
    temperature:
      name: "Room sensor Temperature"
      filters:
        - offset: -3.0
    humidity:
      name: "Room sensor Humidity"
    update_interval: 60s
button:
  - platform: template
    name: "Calibrate Fresh Air (400ppm)"
    on_press:
      - lambda: 'id(my_cozir)->calibrate_fresh_air();'
      
  - platform: template
    name: "Calibrate Nitrogen (0ppm)"
    on_press:
      - lambda: 'id(my_cozir)->calibrate_nitrogen();'

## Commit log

2026-01-22 new layout
    [room-pcb.kicad_pcb, room-pcb.kicad_sch]
2026-02-04 first order
    [bom.csv, designators.csv, positions.csv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]
2026-02-08 first order with cozir fix and i2c fix
    [bom.csv, designators.csv, positions.csv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]
2026-02-17 add quantile filter
2026-02-17 new layout order 2
    [bom.csv, designators.csv, positions.csv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]
2026-02-17 esphome code
    [bom.csv, designators.csv, positions.csv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]
2026-02-17 add pcb info
    [bom.csv, designators.csv, positions.csv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]
2026-02-17 added 3d model
    [home sensor v21.step]
2026-03-30 correct hole pcb
    [home sensor v21.step, home sensor v31.step, room-pcb.kicad_pcb]
2026-04-10 with new gerbers
    [positions.csv]
2026-04-11 nice silk now
    [positions.csv, room-pcb.kicad_pcb]
2026-05-27 Add open source hardware project structure
    Adds the foundational OSH documentation and repo hygiene files to
    make the Room Sensor project properly open-sourceable:
    - README.md: full project overview with sensors table, prominent AC
    mains safety warning, ESPHome and Zigbee setup sections, hardware
    version history, and BOM/Gerber references
    - LICENSE: CERN OHL-S v2 (Strongly Reciprocal) for hardware designs
    - CONTRIBUTING.md: contribution guide covering issues, PRs, KiCad 8
    version requirements, secrets handling, and AC mains review note
    - CHANGELOG.md: seeded with v3 → v3.1 → v4 → v4.1 history
    - .gitignore: KiCad-specific rules excluding lock files, backups,
    .history/, ESPHome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
